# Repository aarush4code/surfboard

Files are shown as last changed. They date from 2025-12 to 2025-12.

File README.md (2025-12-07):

# surfboard

This is a devboard made with rp2040. It has 40 pins and 3 LEDs.

While making the devboard, or surfboard, I learned more about creating things in the kicad shematic, and how to route wires when their is a tight space. I also learned how to add labels to wire components together in the schematic.

## Images








## Bill of Materials
| Item | Unit Price ($) | Link | Quantity | Total ($) |
|---|---|---|---|---|
| Capacitor 0.1uF | 0.30 | [C52923](https://www.lcsc.com/product-detail/C52923.html?s_z=n_CL05A105KA5NQNC) | 11 | 3.30 |
| Capacitor 33pF | 0.10 | [C1562](https://www.lcsc.com/product-detail/C1562.html?s_z=n_0402CG330J500NT) | 2 | 0.20 |
| Capacitor 1uF | 0.25 | [C42431804](https://www.lcsc.com/product-detail/C42431804.html) | 2 | 0.50 |
| Capacitor 10uF | 0.29 | [C19702](https://www.lcsc.com/product-detail/C19702.html?s_z=n_CL10A106KP8NNNC) | 2 | 0.58 |
| Resistor 27Ω | 0.60 | [C25100](https://www.lcsc.com/product-detail/C25100.html) | 2 | 1.20 |
| Resistor 1KΩ | 0.06 | [C11702](https://www.lcsc.com/product-detail/C11702.html?s_z=n_0402WGF1001TCE)  | 2 | 0.12 |
| Resistor 5.1KΩ | 0.05 | [C25905](https://www.lcsc.com/product-detail/C25905.html?s_z=n_0402WGF5101TCE)  | 2 | 0.10 |
| Resistor 10KΩ | 0.06 | [C25744](https://www.lcsc.com/product-detail/C25744.html?s_z=n_0402WGF1002TCE)  | 1 | 0.06 |
| SK6812MINI LED | 0.43 | [C5149201](https://www.lcsc.com/product-detail/C5149201.html) | 3 | 1.29 |
| 1x03 Pin Header | 0.00 | [C42431804](https://www.lcsc.com/product-detail/C42431804.html) | 1 | 0.00 |
| 1x20 Pin Header | 0.17 | [C42431804](https://www.lcsc.com/product-detail/C42431804.html) | 2 | 0.34 |
| 12 MHz Crystal | 0.67 | [C9002](https://www.lcsc.com/product-detail/C9002.html?s_z=n_X322512MSB4SI) | 1 | 0.67 |
| USB-C Receptacle | 0.88 | [C165948](https://www.lcsc.com/product-detail/C165948.html?s_z=n_TYPE-C-31-M-12)| 1 | 0.88 |
| Flash Memory | 0.95 | [C179171](https://www.lcsc.com/product-detail/C179171.html?s_z=n_Winbond%2520W25Q128JVSs) | 1 | 1.60 |
| Voltage Regulator | 0.33 | [C3054](https://www.lcsc.com/product-detail/C3054.html?s_z=n_IRFL9014TRPBF) | 1 | 1.36 |
| Button | 0.42 | [C2891841](https://www.lcsc.com/product-detail/C2891841.html) | 1 | 0.42 |
| RP2040 | 0.95 | [C2040](https://www.lcsc.com/product-detail/C2040.html?s_z=n_RP2040) | 1 | 0.95 |
| PCBA | 44.02 | [JLCPCB](https://jlcpcb.com) | 1 | 44.02 |
| **Total** | -- | — | — | **57.89** |

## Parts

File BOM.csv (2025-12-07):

Name | Cost | Link | Quantity
Capacitor .1uF | 0.3 | https://www.lcsc.com/product-detail/C52923.html?s_z=n_CL05A105KA5NQNC | 11
Capacitor 33pF | 0.1 | https://www.lcsc.com/product-detail/C1562.html?s_z=n_0402CG330J500NT | 2
Capacitor 1uF | 0.25 | https://www.lcsc.com/product-detail/C42431804.html | 2
Capacitor 10uF | 0.29 | https://www.lcsc.com/product-detail/C19702.html?s_z=n_CL10A106KP8NNNC | 2
Resistor 27 | 0.6 | https://www.lcsc.com/product-detail/C25100.html | 2
Resistor 1K | 0.06 | https://www.lcsc.com/product-detail/C11702.html?s_z=n_0402WGF1001TCE | 2
Resistor 5.1K | 0.05 | https://www.lcsc.com/product-detail/C25905.html?s_z=n_0402WGF5101TCE | 2
Resistor 10K | 0.06 | https://www.lcsc.com/product-detail/C25744.html?s_z=n_0402WGF1002TCE | 1
SK6812MINI LED | 0.43 | https://www.lcsc.com/product-detail/C5149201.html | 3
1x03 Pin Header | 0 | https://www.lcsc.com/product-detail/C42431804.html | 1
1x20 Pin Header | 0.17 | https://www.lcsc.com/product-detail/C42431804.html | 2
12 Mhz Crystal | 0.67 | https://www.lcsc.com/product-detail/C9002.html?s_z=n_X322512MSB4SI | 1
USB C Receptacle | 0.88 | https://www.lcsc.com/product-detail/C165948.html?s_z=n_TYPE-C-31-M-12 | 1
Flash Memory | 0.95 | https://www.lcsc.com/product-detail/C179171.html?s_z=n_Winbond%2520W25Q128JVSs | 1
Voltage Regulator | 0.33 | https://www.lcsc.com/product-detail/C2891841.html | 1
Button | 0.42 | https://www.lcsc.com/product-detail/C720477.html
RP2040 | 0.95 | https://www.lcsc.com/product-detail/C2040.html?s_z=n_RP2040 | 1
PCBA | 44.02 | jlcpcb.com | 1
Total | 50.53

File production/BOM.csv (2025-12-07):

Id | Designator | Footprint | Quantity | Designation | Supplier and ref
1 | C11,C12,C17,C8,C3,C9,C4,C1,C7,C6,C5 | C_0402_1005Metric | 11 | .1uF
2 | C2,C10 | C_0402_1005Metric | 2 | 1uF
3 | U3 | Winbond_USON-8-1EP_3x2mm_P0.5mm_EP0.2x1.6mm | 1 | W25Q16JVSS
4 | U2 | SOT-23 | 1 | MCP1700x-330xxTT
5 | C16,C15 | C_0402_1005Metric | 2 | 33pF
6 | J1 | USB_C_Receptacle_HRO_TYPE-C-31-M-12 | 1 | USB_C_Receptacle_USB2.0_14P
7 | J3,J2 | PinHeader_1x20_P2.54mm_Vertical | 2 | Conn_01x20
8 | R2,R7 | R_0402_1005Metric | 2 | 1K
9 | C14,C13 | C_0402_1005Metric | 2 | 10uF
10 | D1,D2,D3 | LED_SK6812MINI_PLCC4_3.5x3.5mm_P1.75mm | 3 | SK6812MINI
11 | R5,R4 | R_0402_1005Metric | 2 | 27
12 | J4 | PinHeader_1x03_P2.54mm_Vertical | 1 | Conn_01x03
13 | Y1 | Crystal_SMD_3225-4Pin_3.2x2.5mm | 1 | 12 MHz
14 | R3,R1 | R_0402_1005Metric | 2 | 5.1K
15 | SW1 | SW_Push_SPST_NO_Alps_SKRK | 1 | SW_Push
16 | U1 | QFN-56-1EP_7x7mm_P0.4mm_EP3.2x3.2mm | 1 | RP2040
17 | R6 | R_0402_1005Metric | 1 | 10K

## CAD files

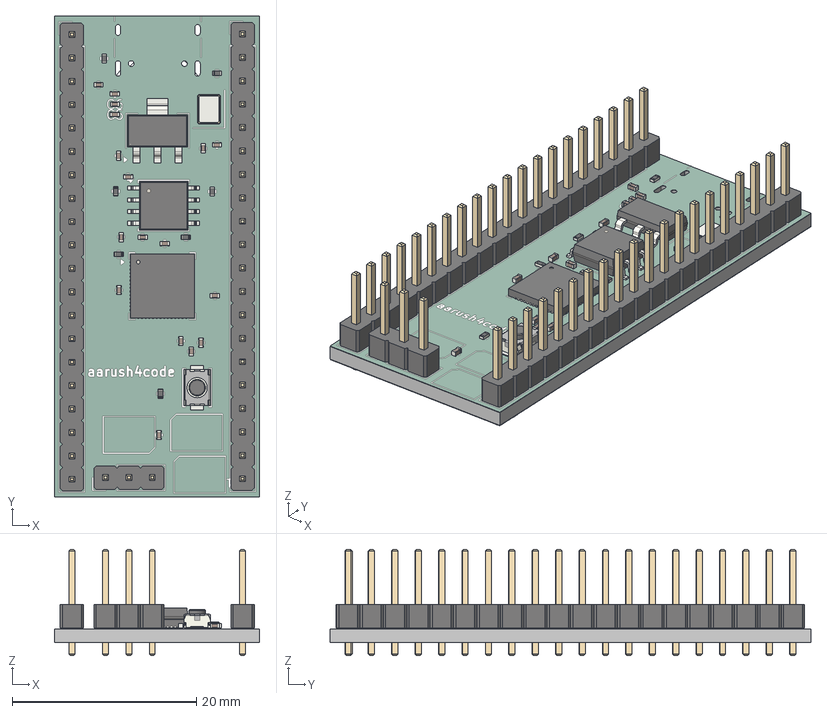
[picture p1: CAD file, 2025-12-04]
cad/devboard.step
22.2 x 52.2 x 11.5 mm
C_0402_1005Metric x 17
SOIC-8_5.3x5.3mm_P1.27mm
PinHeader_1x20_P2.54mm_Vertical x 2
R_0402_1005Metric x 7
PinHeader_1x03_P2.54mm_Vertical
Crystal_SMD_3225-4Pin_3.2x2.5mm
SOT-223
SW_Push_SPST_NO_Alps_SKRK
QFN-56-1EP_7x7mm_P0.4mm_EP3.2x3.2mm
Devboard_silkscreen x 2
Devboard_soldermask x 2
Devboard_PCB

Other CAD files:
pcb/devboard.step

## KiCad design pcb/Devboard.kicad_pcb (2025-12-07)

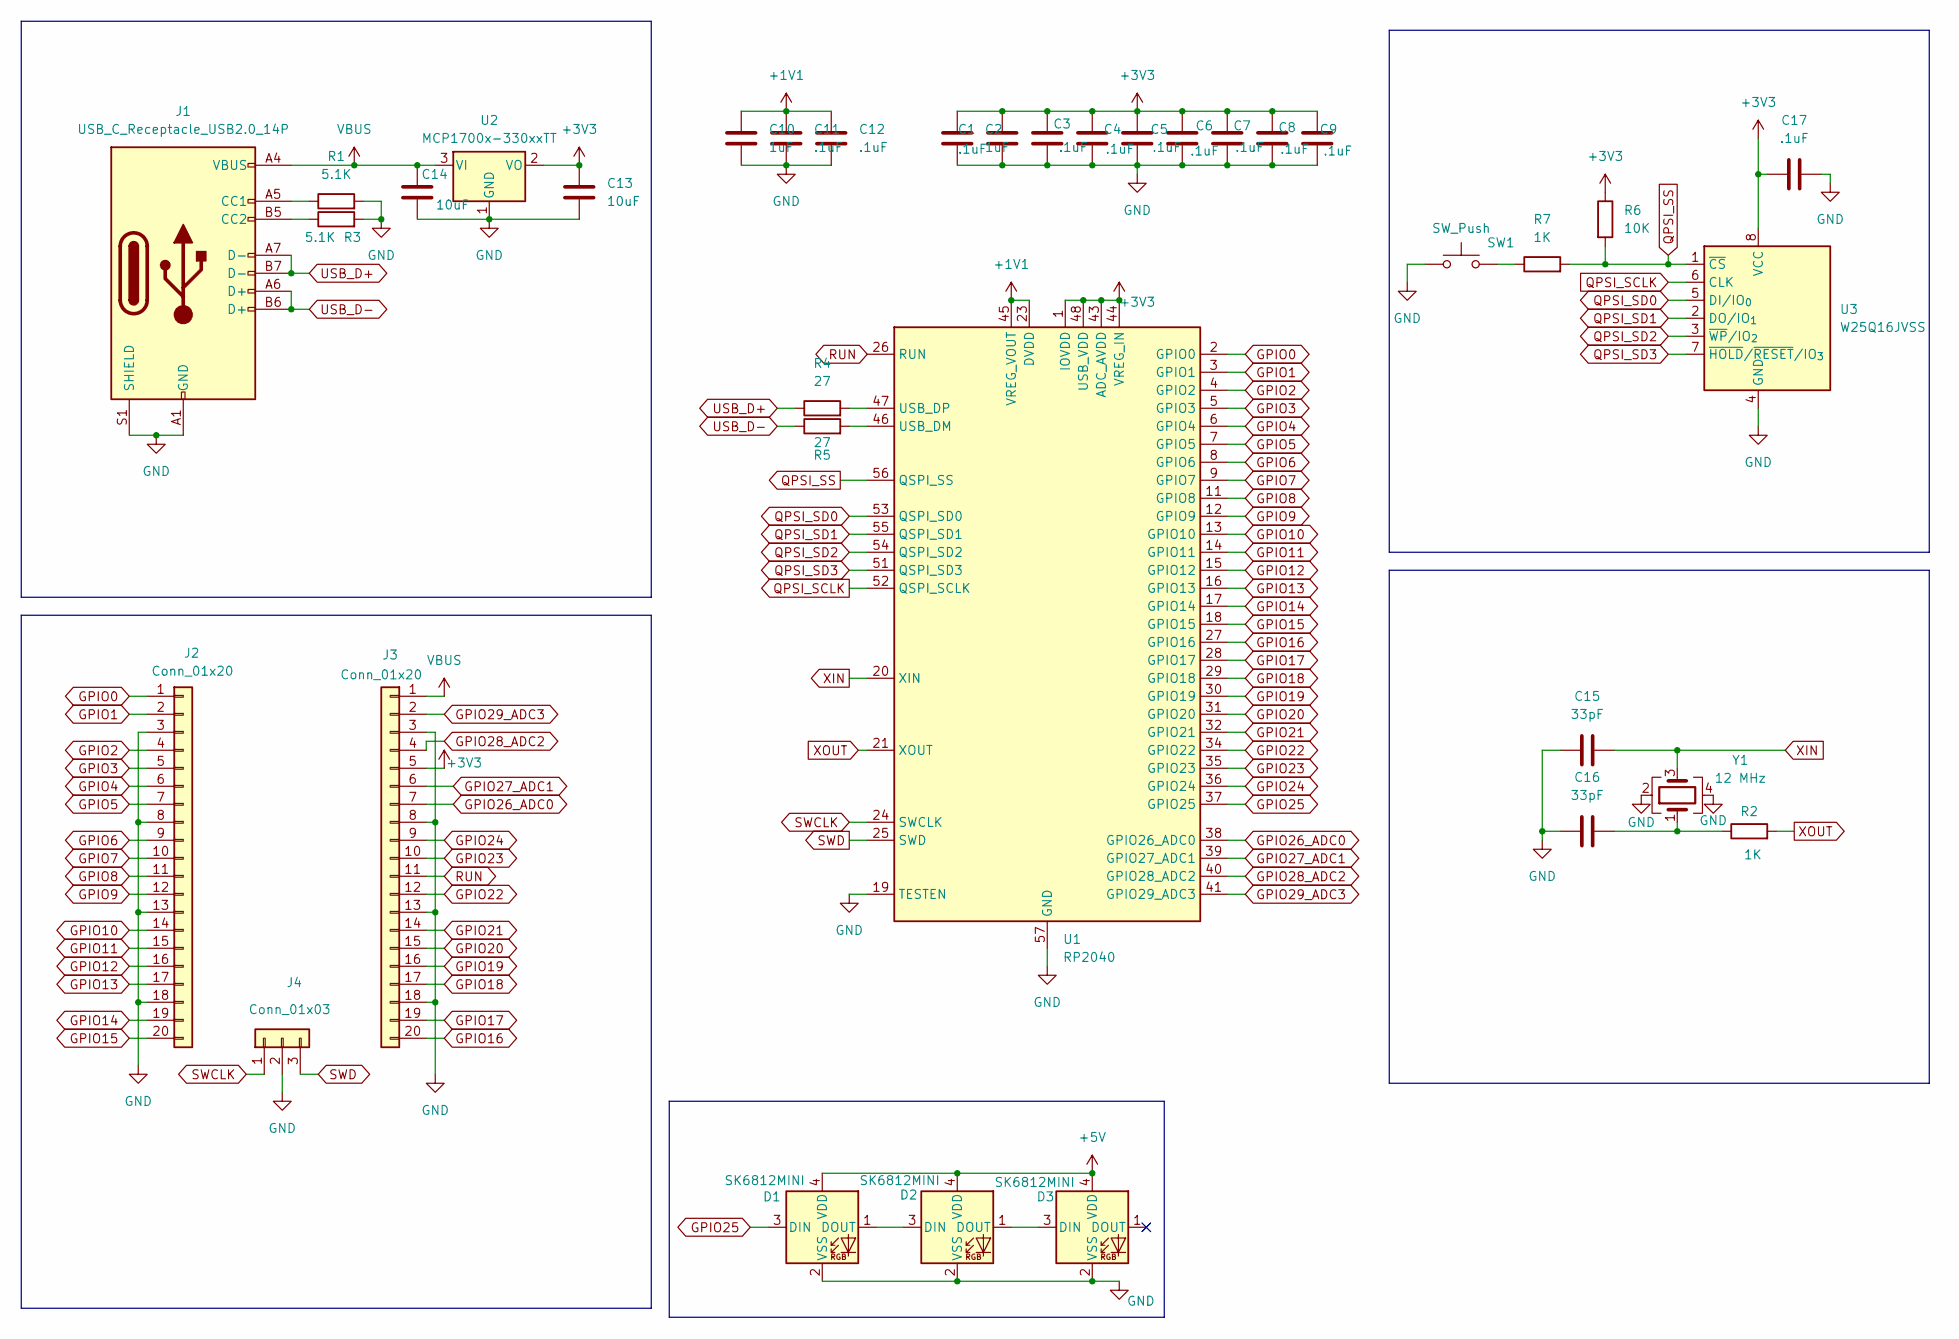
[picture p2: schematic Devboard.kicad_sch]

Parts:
C1, C3, C4, C5, C6, C7, C8, C9, C11, C12, C17: .1uF; C_0402_1005Metric
C2, C10: 1uF; C_0402_1005Metric
C13, C14: 10uF; C_0402_1005Metric
C15, C16: 33pF; C_0402_1005Metric
D1, D2, D3: SK6812MINI; LED_SK6812MINI_PLCC4_3.5x3.5mm_P1.75mm
J1: USB_C_Receptacle_USB2.0_14P; USB_C_Receptacle_HRO_TYPE-C-31-M-12
J2, J3: Conn_01x20; PinHeader_1x20_P2.54mm_Vertical
J4: Conn_01x03; PinHeader_1x03_P2.54mm_Vertical
R1, R3: 5.1K; R_0402_1005Metric
R2, R7: 1K; R_0402_1005Metric
R4, R5: 27; R_0402_1005Metric
R6: 10K; R_0402_1005Metric
SW1: SW_Push; SW_Push_SPST_NO_Alps_SKRK
U1: RP2040; QFN-56-1EP_7x7mm_P0.4mm_EP3.2x3.2mm
U2: MCP1700x-330xxTT; SOT-23
U3: W25Q16JVSS; Winbond_USON-8-1EP_3x2mm_P0.5mm_EP0.2x1.6mm
Y1: 12 MHz; Crystal_SMD_3225-4Pin_3.2x2.5mm

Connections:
+1V1: C10.1, C11.1, C12.1, U1.23 (DVDD), U1.45 (VREG_VOUT), U1.50 (DVDD)
+3V3: C1.1, C2.1, C3.1, C4.1, C5.1, C6.1, C7.1, C8.1, C9.1, C13.1, C17.1, J3.5, R6.1, U1.1 (IOVDD), U1.10 (IOVDD), U1.22 (IOVDD), U1.33 (IOVDD), U1.42 (IOVDD), U1.43 (ADC_AVDD), U1.44 (VREG_IN), U1.48 (USB_VDD), U1.49 (IOVDD), U2.2 (VO), U3.8 (VCC)
+5V: D1.4 (VDD), D2.4 (VDD), D3.4 (VDD)
GND: C1.2, C2.2, C3.2, C4.2, C5.2, C6.2, C7.2, C8.2, C9.2, C10.2, C11.2, C12.2, C13.2, C14.2, C15.1, C16.1, C17.2, D1.2 (VSS), D2.2 (VSS), D3.2 (VSS), J1.A1 (GND), J1.A12 (GND), J1.B1 (GND), J1.B12 (GND), J1.S1 (SHIELD), J2.3, J2.8, J2.13, J2.18, J3.3, J3.8, J3.13, J3.18, J4.2, R1.2, R3.2, SW1.1, U1.19 (TESTEN), U1.57 (GND), U2.1 (GND), U3.4 (GND), Y1.2, Y1.4
GPIO0: J2.1, U1.2 (GPIO0)
GPIO1: J2.2, U1.3 (GPIO1)
GPIO2: J2.4, U1.4 (GPIO2)
GPIO3: J2.5, U1.5 (GPIO3)
GPIO4: J2.6, U1.6 (GPIO4)
GPIO5: J2.7, U1.7 (GPIO5)
GPIO6: J2.9, U1.8 (GPIO6)
GPIO7: J2.10, U1.9 (GPIO7)
GPIO8: J2.11, U1.11 (GPIO8)
GPIO9: J2.12, U1.12 (GPIO9)
GPIO10: J2.14, U1.13 (GPIO10)
GPIO11: J2.15, U1.14 (GPIO11)
GPIO12: J2.16, U1.15 (GPIO12)
GPIO13: J2.17, U1.16 (GPIO13)
GPIO14: J2.19, U1.17 (GPIO14)
GPIO15: J2.20, U1.18 (GPIO15)
GPIO16: J3.20, U1.27 (GPIO16)
GPIO17: J3.19, U1.28 (GPIO17)
GPIO18: J3.17, U1.29 (GPIO18)
GPIO19: J3.16, U1.30 (GPIO19)
GPIO20: J3.15, U1.31 (GPIO20)
GPIO21: J3.14, U1.32 (GPIO21)
GPIO22: J3.12, U1.34 (GPIO22)
GPIO23: J3.10, U1.35 (GPIO23)
GPIO24: J3.9, U1.36 (GPIO24)
GPIO25: D1.3 (DIN), U1.37 (GPIO25)
GPIO26_ADC0: J3.7, U1.38 (GPIO26_ADC0)
GPIO27_ADC1: J3.6, U1.39 (GPIO27_ADC1)
GPIO28_ADC2: J3.4, U1.40 (GPIO28_ADC2)
GPIO29_ADC3: J3.2, U1.41 (GPIO29_ADC3)
unnamed: C16.2, R2.1, Y1.1
unnamed: D1.1 (DOUT), D2.3 (DIN)
unnamed: D2.1 (DOUT), D3.3 (DIN)
unnamed: J1.A5 (CC1), R1.1
unnamed: J1.B5 (CC2), R3.1
unnamed: R7.1, SW1.2
unnamed: R5.2, U1.46 (USB_DM)
unnamed: R4.2, U1.47 (USB_DP)
QPSI_SCLK: U1.52 (QSPI_SCLK), U3.6 (CLK)
QPSI_SD0: U1.53 (QSPI_SD0), U3.5 (DI/IO_{0})
QPSI_SD1: U1.55 (QSPI_SD1), U3.2 (DO/IO_{1})
QPSI_SD2: U1.54 (QSPI_SD2), U3.3 (~WP/IO_{2})
QPSI_SD3: U1.51 (QSPI_SD3), U3.7 (~HOLD/~RESET/IO_{3})
QPSI_SS: R6.2, R7.2, U1.56 (QSPI_SS), U3.1 (~CS)
RUN: J3.11, U1.26 (RUN)
SWCLK: J4.1, U1.24 (SWCLK)
SWD: J4.3, U1.25 (SWD)
USB_D+: J1.A7 (D-), J1.B7 (D-), R4.1
USB_D-: J1.A6 (D+), J1.B6 (D+), R5.1
VBUS: C14.1, J1.A4 (VBUS), J1.A9 (VBUS), J1.B4 (VBUS), J1.B9 (VBUS), J3.1, U2.3 (VI)
XIN: C15.2, U1.20 (XIN), Y1.3
XOUT: R2.2, U1.21 (XOUT)

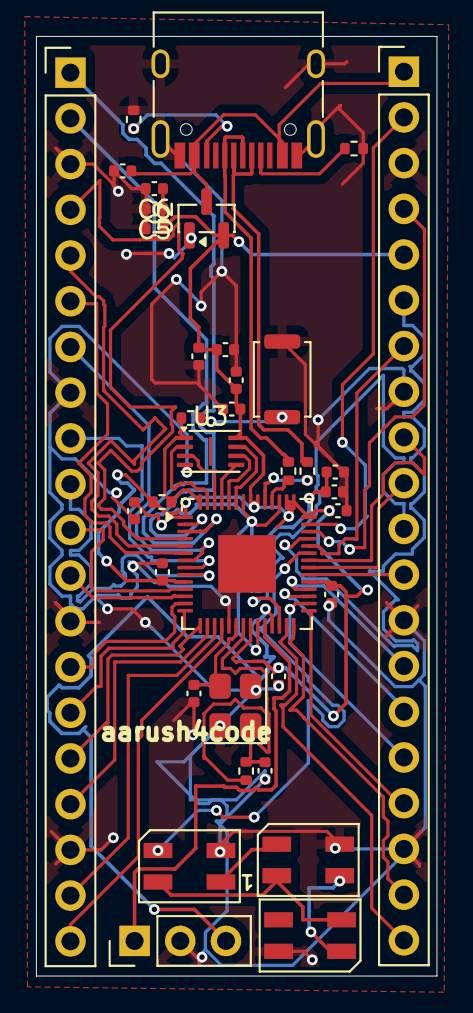
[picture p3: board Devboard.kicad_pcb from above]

Board: 2 copper layers, 22.2 x 52.2 mm, 36 parts (0 on the bottom side), 56 nets.

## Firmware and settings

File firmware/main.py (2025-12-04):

import array, time
from machine import Pin
import rp2

@rp2.asm_pio(sideset_init=rp2.PIO.OUT_LOW,
             out_shiftdir=rp2.PIO.SHIFT_LEFT,
             autopull=True, pull_thresh=24)
def ws2812():
    T1 = 2
    T2 = 5
    T3 = 3
    wrap_target()
    label("bitloop")
    out(x, 1)               .side(0)    [T3 - 1]
    jmp(not_x, "do_zero")   .side(1)    [T1 - 1]
    jmp("bitloop")          .side(1)    [T2 - 1]
    label("do_zero")
    nop()                   .side(0)    [T2 - 1]
    wrap()

sm = rp2.StateMachine(0, ws2812, freq=8_000_000, sideset_base=Pin(25))
sm.active(1)

NUM_LEDS = 3
ar = array.array("I", [0 for _ in range(NUM_LEDS)])

for i in range(10):
    ar[0] = (0 << 16) | (8 << 8) | 0   
    ar[1] = (8 << 16) | (0 << 8) | 0  
    ar[2] = (0 << 16) | (0 << 8) | 8  
    sm.put(ar) 
    time.sleep_ms(300)

    ar[0] = ar[1] = ar[2] = 0
    sm.put(ar)
    time.sleep_ms(300)

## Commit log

2025-12-04 added cad
    [devboard.step]
2025-12-04 added bom
    [BOM.csv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]
2025-12-04 added bom to readme
2025-12-07 updated routing
    [BOM.csv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]
2025-12-07 updated bom
    [BOM.csv]
